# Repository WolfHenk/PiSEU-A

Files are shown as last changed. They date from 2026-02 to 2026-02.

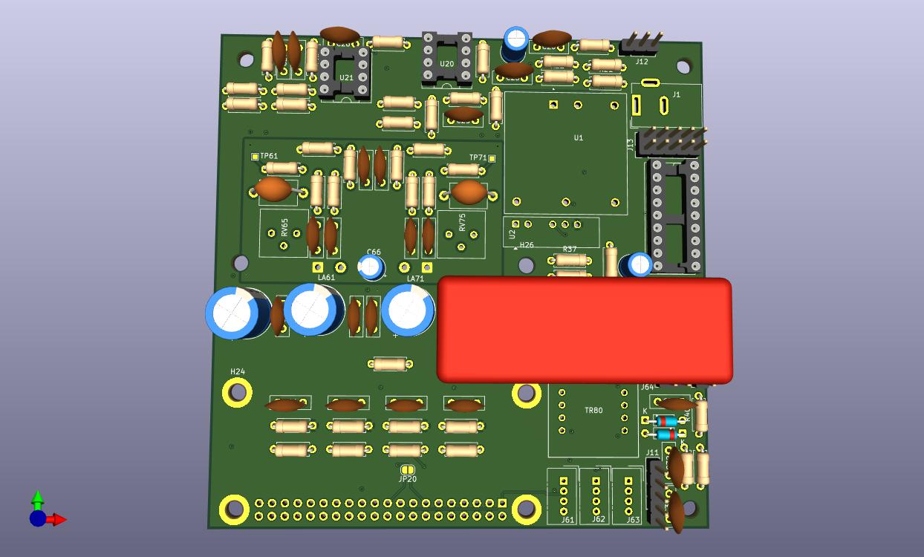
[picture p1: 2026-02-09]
PiSEU-A-v4-discrete.jpg

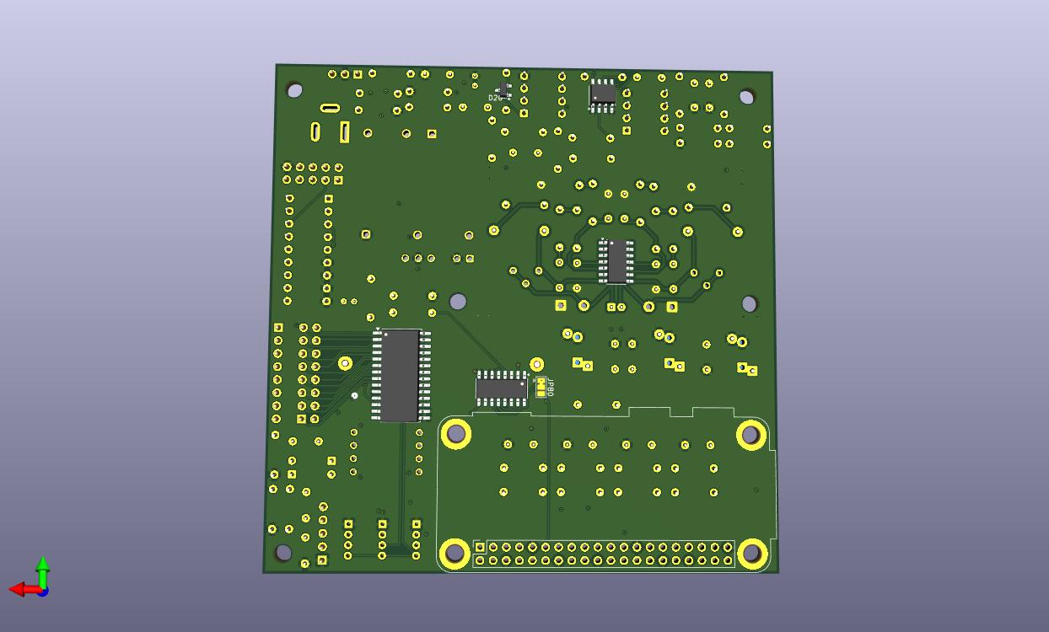
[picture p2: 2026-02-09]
PiSEU-A-v4-discrete-R.jpg

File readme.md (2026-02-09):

THE SEU (Sende-Empfangs-Umsetzer) translates TW39 to ED1000 and vice versa

SEU-A was at "Amt" the networks side of the line. SEU-B was at the telex at costumers side.

This card emulates SEU-A and sits between raspberry Pi (piTelex) and a ED1000 and works as a kind of modem between piTelex TXD and RXD and Telex

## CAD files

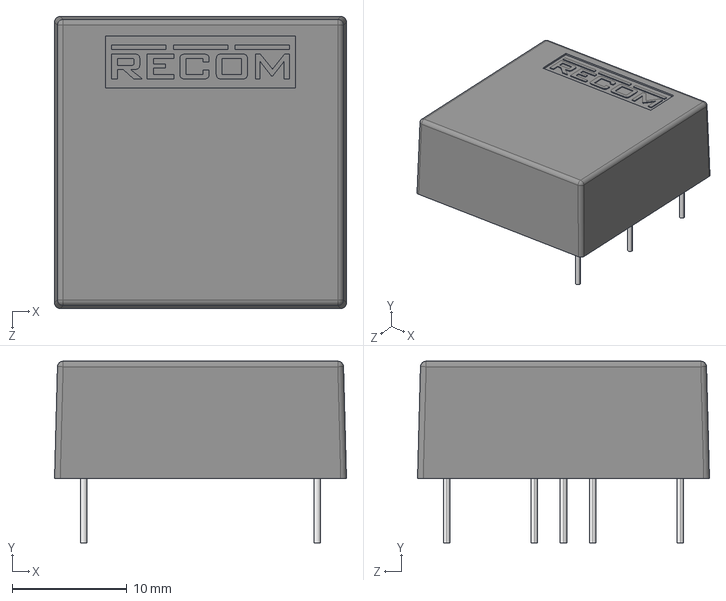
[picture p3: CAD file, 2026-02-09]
REC10K-2405DAW_H2/REC10K-2405DAW_H2.step
25.4 x 15.8 x 25.4 mm

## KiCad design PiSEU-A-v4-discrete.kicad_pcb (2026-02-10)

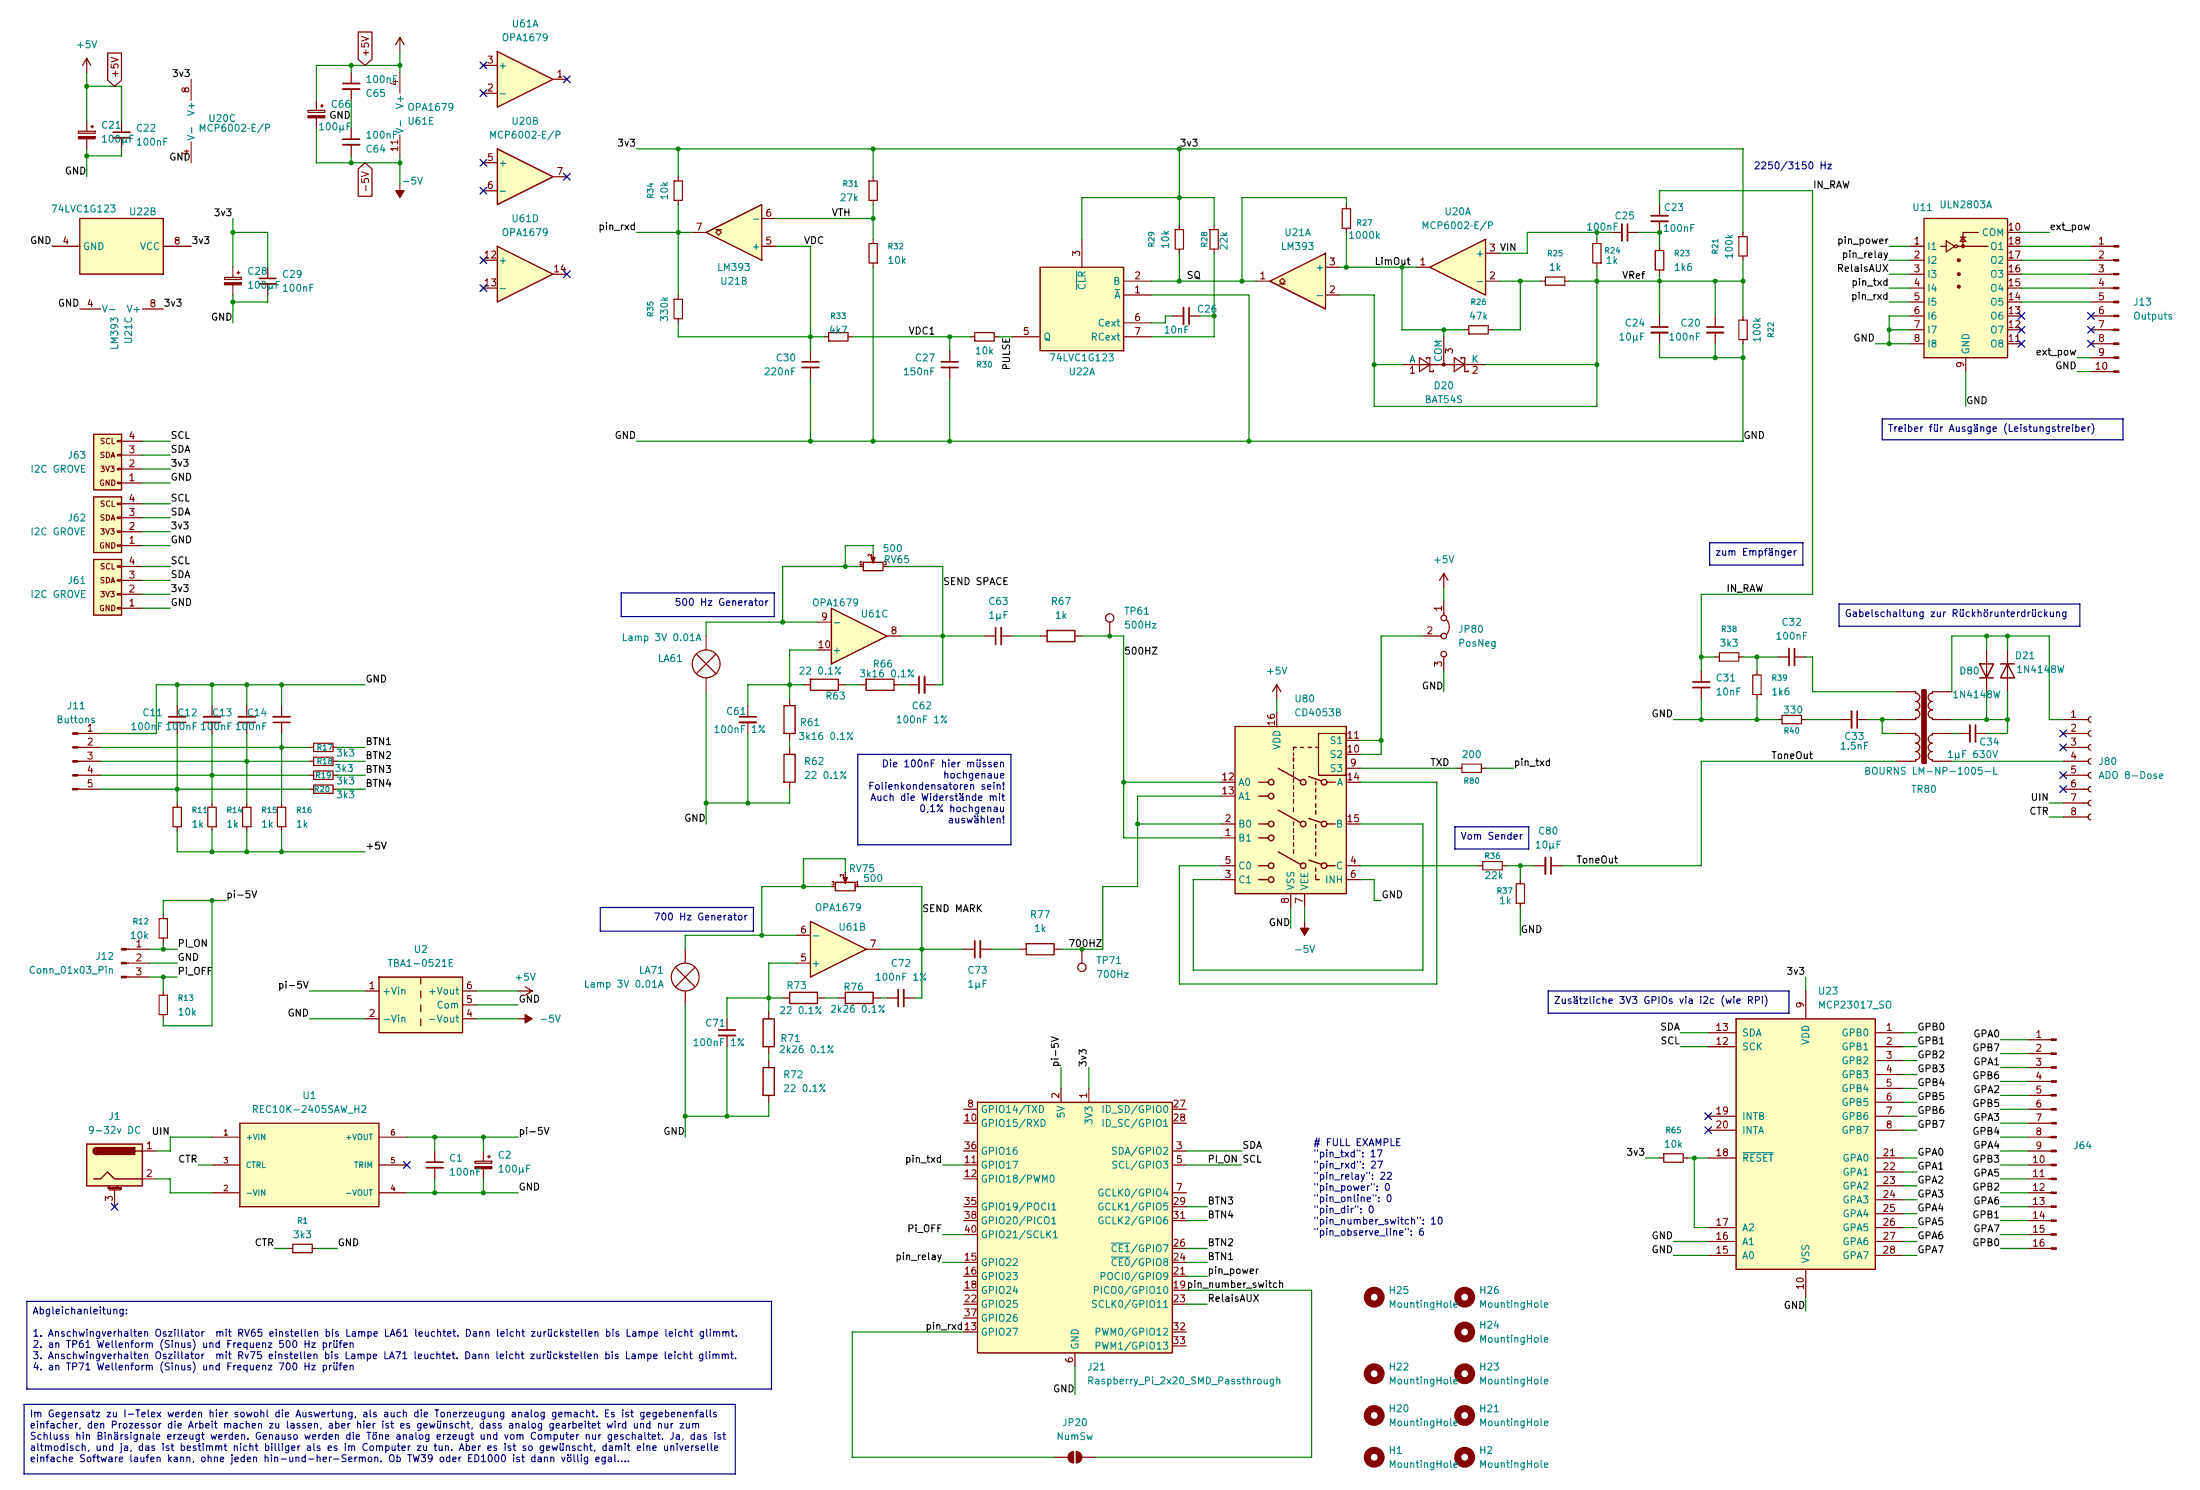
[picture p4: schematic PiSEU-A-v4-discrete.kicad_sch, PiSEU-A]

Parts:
C1, C11, C12, C13, C14, C20, C22, C23, C25, C29, C32, C64, C65: 100nF; C_Disc_D4.7mm_W2.5mm_P5.00mm; JLCPCB Part # C1590
C2, C21, C28: 100µF; CP_Radial_D6.3mm_P2.50mm; JLCPCB Part # C3338
C24, C80: 10µF; C_Radial_D5.0mm_H7.0mm_P2.00mm
C26, C31: 10nF; C_Disc_D5.0mm_W2.5mm_P2.50mm
C27: 150nF; C_Rect_L7.0mm_W4.5mm_P5.00mm; JLCPCB Part # C1597
C30: 220nF; C_Rect_L7.0mm_W4.5mm_P5.00mm; JLCPCB Part # C21120
C33: 1.5nF; C_Disc_D4.7mm_W2.5mm_P5.00mm; Part Number ggtt; JLCPCB Part # C1595
C34: 1µF 630V; C_Rect_L41.5mm_W15.0mm_P37.50mm_MKS4
C61, C62, C71, C72: 100nF 1%; C_Disc_D8.0mm_W2.5mm_P5.00mm
C63, C73: 1µF; C_Rect_L4.6mm_W3.8mm_P2.50mm_MKS02_FKP02; JLCPCB Part # C15849
C66: 100µF; CP_Radial_D6.3mm_P2.50mm
D20: BAT54S; SOT-23
D21, D80: 1N4148W; D_DO-35_SOD27_P7.62mm_Horizontal
H1, H2, H20, H21, H22, H23, H24, H25, H26: MountingHole; MountingHole_3.2mm_M3
J1: 9-32v DC; BarrelJack_Wuerth_6941xx301002
J11: Buttons; PinHeader_1x05_P2.54mm_Vertical
J12: Conn_01x03_Pin; PinHeader_1x03_P2.54mm_Vertical
J13: Outputs; PinHeader_2x05_P2.54mm_Vertical
J21: Raspberry_Pi_2x20_SMD_Passthrough; Raspberry_Pi_Zero_Socketed_THT_FaceDown_MountingHoles
J61, J62, J63: I2C GROVE; NS-Tech_Grove_1x04_P2mm_Vertical
J64: I2C-OUTPUTS; PinHeader_2x08_P2.54mm_Vertical; Part Number 1-1602FBV0T
J80: ADO 8-Dose; PinHeader_1x08_P2.54mm_Vertical
JP20: NumSw; SolderJumper-2_P1.3mm_Open_RoundedPad1.0x1.5mm
JP80: PosNeg; SolderJumper-3_P1.3mm_Bridged12_Pad1.0x1.5mm
LA61, LA71: Lamp 3V 0.01A; SolderWire-0.5sqmm_1x02_P4.6mm_D0.9mm_OD2.1mm
R1, R17, R18, R19, R20, R38: 3k3; R_Axial_DIN0207_L6.3mm_D2.5mm_P7.62mm_Horizontal; JLCPCB Part # C22978
R11, R14, R15, R16, R24, R25, R37, R67, R77: 1k; R_Axial_DIN0207_L6.3mm_D2.5mm_P7.62mm_Horizontal; JLCPCB Part # C21190
R12, R13, R29, R30, R32, R34, R65: 10k; R_Axial_DIN0207_L6.3mm_D2.5mm_P7.62mm_Horizontal; JLCPCB Part # C25804
R21, R22: 100k; R_Axial_DIN0207_L6.3mm_D2.5mm_P7.62mm_Horizontal; JLCPCB Part # C25803
R23, R39: 1k6; R_Axial_DIN0207_L6.3mm_D2.5mm_P7.62mm_Horizontal
R26: 47k; R_Axial_DIN0207_L6.3mm_D2.5mm_P7.62mm_Horizontal; JLCPCB Part # C25600
R27: 1000k; R_Axial_DIN0207_L6.3mm_D2.5mm_P7.62mm_Horizontal; JLCPCB Part # C22935
R28, R36: 22k; R_Axial_DIN0207_L6.3mm_D2.5mm_P7.62mm_Horizontal; JLCPCB Part # C31850
R31: 27k; R_Axial_DIN0207_L6.3mm_D2.5mm_P7.62mm_Horizontal; JLCPCB Part # C22967
R33: 4k7; R_Axial_DIN0207_L6.3mm_D2.5mm_P7.62mm_Horizontal
R35: 330k; R_Axial_DIN0207_L6.3mm_D2.5mm_P7.62mm_Horizontal
R40: 330; R_Axial_DIN0207_L6.3mm_D2.5mm_P7.62mm_Horizontal; JLCPCB Part # C23138
R61, R66: 3k16 0.1%; R_Axial_DIN0207_L6.3mm_D2.5mm_P7.62mm_Horizontal
R62, R63, R72, R73: 22 0.1%; R_Axial_DIN0207_L6.3mm_D2.5mm_P7.62mm_Horizontal
R71, R76: 2k26 0.1%; R_Axial_DIN0207_L6.3mm_D2.5mm_P7.62mm_Horizontal
R80: 200; R_Axial_DIN0207_L6.3mm_D2.5mm_P7.62mm_Horizontal; JLCPCB Part # C8218
RV65, RV75: 500; Potentiometer_Bourns_3386P_Vertical
TP61: 500Hz; TestPoint_Pad_1.0x1.0mm
TP71: 700Hz; TestPoint_Pad_1.0x1.0mm
TR80: BOURNS LM-NP-1005-L; TRANS_LM-NP-1005L_BRN
U1: REC10K-2405SAW_H2; CONV_REC10K-2405SAW_H2
U2: TBA1-0521E; Converter_DCDC_TRACO_TBA1-xxxxE_Dual_THT
U11: ULN2803A; DIP-18_W7.62mm_Socket
U20: MCP6002‑E/P; DIP-8_W7.62mm_Socket
U21: LM393; DIP-8_W7.62mm_Socket
U22: 74LVC1G123; SSOP-8_3.9x5.05mm_P1.27mm
U23: MCP23017_SO; SOIC-28W_7.5x17.9mm_P1.27mm
U61: OPA1679; SOIC-14_3.9x8.7mm_P1.27mm
U80: CD4053B; SOIC-16_3.9x9.9mm_P1.27mm; JLCPCB Part # C6742

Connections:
+5V: C21.1, C22.1, C65.1, C66.1, JP80.1 (A), R11.1, R14.1, R15.1, R16.1, U2.6 (+Vout), U61.4 (V+), U80.16 (VDD)
-5V: C64.2, C66.2, U2.4 (-Vout), U61.11 (V-), U80.7 (VEE)
/3v3: C28.1, C29.1, J21.1 (3V3), J21.17 (3V3), J61.2, J62.2, J63.2, R21.1, R28.1, R29.1, R31.1, R34.1, R65.1, U20.8 (V+), U21.8 (V+), U22.3 (~CLR), U22.8 (VCC), U23.9 (VDD)
/500HZ: R67.1, TP61.1, U80.1 (B1), U80.12 (A0)
/700HZ: R77.1, TP71.1, U80.2 (B0), U80.13 (A1)
/BTN1: J21.24 (~CE0/GPIO8), R17.2
/BTN2: J21.26 (~CE1/GPIO7), R18.2
/BTN3: J21.29 (GCLK1/GPIO5), R19.2
/BTN4: J21.31 (GCLK2/GPIO6), R20.2
/CTR: J80.8, R1.1, U1.3 (CTRL)
/GND: C1.2, C2.2, C11.2, C12.2, C13.2, C14.2, C20.2, C21.2, C22.2, C24.2, C27.2, C28.2, C29.2, C30.2, C31.2, C61.2, C64.1, C65.2, C71.2, J11.1, J12.2, J13.10, J21.6 (GND), J21.9 (GND), J21.14 (GND), J21.20 (GND), J21.25 (GND), J21.30 (GND), J21.34 (GND), J21.39 (GND), J61.1, J62.1, J63.1, JP80.3 (B), LA61.1 (-), LA71.1 (-), R1.2, R22.1, R32.1, R37.1, R39.1, R40.1, R62.2, R72.2, U1.4 (-VOUT), U2.2 (-Vin), U2.5 (Com), U11.6 (I6), U11.7 (I7), U11.8 (I8), U11.9 (GND), U20.4 (V-), U21.4 (V-), U22.1 (~A), U22.4 (GND), U23.10 (VSS), U23.15 (A0), U23.16 (A1), U80.6 (INH), U80.8 (VSS)
/GPA0: J64.1, U23.21 (GPA0)
/GPA1: J64.3, U23.22 (GPA1)
/GPA2: J64.5, U23.23 (GPA2)
/GPA3: J64.7, U23.24 (GPA3)
/GPA4: J64.9, U23.25 (GPA4)
/GPA5: J64.11, U23.26 (GPA5)
/GPA6: J64.13, U23.27 (GPA6)
/GPA7: J64.15, U23.28 (GPA7)
/GPB0: J64.16, U23.1 (GPB0)
/GPB1: J64.14, U23.2 (GPB1)
/GPB2: J64.12, U23.3 (GPB2)
/GPB3: J64.10, U23.4 (GPB3)
/GPB4: J64.8, U23.5 (GPB4)
/GPB5: J64.6, U23.6 (GPB5)
/GPB6: J64.4, U23.7 (GPB6)
/GPB7: J64.2, U23.8 (GPB7)
/IN_RAW: C23.1, C31.1, R38.1
/LimOut: D20.3 (COM), R26.1, R27.1, U20.1, U21.3 (+)
/PI_ON: J12.1, J21.5 (SCL/GPIO3), J61.4, J62.4, J63.4, R12.2, U23.12 (SCK)
/PULSE: R30.2, U22.5 (Q)
/Pi_OFF: J12.3, J21.40 (GPIO21/SCLK1), R13.1
/RelaisAUX: J21.23 (SCLK0/GPIO11), U11.3 (I3)
/SDA: J21.3 (SDA/GPIO2), J61.3, J62.3, J63.3, U23.13 (SDA)
/SEND MARK: C72.2, C73.1, RV75.1, U61.7
/SEND SPACE: C62.2, C63.1, RV65.3, U61.8
/SQ: R27.2, R29.2, U21.1, U22.2 (B)
/TXD: R80.2, U80.9 (S3)
/ToneOut: C80.1, TR80.8
/UIN: J1.1, J80.7, U1.1 (+VIN)
/VDC: C30.1, R33.1, R35.2, U21.5 (+)
/VDC1: C27.1, R30.1, R33.2
/VIN: C25.2, R24.2, U20.3 (+)
/VRef: C20.1, C24.1, D20.1 (A), D20.2 (K), R21.2, R22.2, R23.1, R24.1, R25.2, U21.2 (-)
/VTH: R31.2, R32.2, U21.6 (-)
/ext_pow: J13.9, U11.10 (COM)
/pi-5V: C1.1, C2.1, J21.2 (5V), J21.4 (5V), R12.1, R13.2, U1.6 (+VOUT), U2.1 (+Vin)
/pin_number_switch: J21.19 (PICO0/GPIO10), JP20.2 (B)
/pin_power: J21.21 (POCI0/GPIO9), U11.1 (I1)
/pin_relay: J21.15 (GPIO22), U11.2 (I2)
/pin_rxd: J21.13 (GPIO27), JP20.1 (A), R34.2, R35.1, U11.5 (I5), U21.7
/pin_txd: J21.11 (GPIO17), R80.1, U11.4 (I4)
unnamed: C23.2, C25.1, R23.2
unnamed: C32.1, TR80.5
unnamed: C32.2, R38.2, R39.2
unnamed: C33.1, TR80.6, TR80.7
unnamed: C33.2, R40.2
unnamed: C34.2, TR80.2
unnamed: C62.1, R66.1
unnamed: C63.2, R67.2
unnamed: C72.1, R76.1
unnamed: C73.2, R77.2
unnamed: C80.2, R36.2, R37.2
unnamed: C34.1, D21.2 (A), D80.1 (K), TR80.3
unnamed: D21.1 (K), D80.2 (A), J80.1, TR80.4
unnamed: C14.1, J11.2, R16.2, R17.1
unnamed: C13.1, J11.3, R15.2, R18.1
unnamed: C12.1, J11.4, R14.2, R19.1
unnamed: C11.1, J11.5, R11.2, R20.1
unnamed: J13.1, U11.18 (O1)
unnamed: J13.2, U11.17 (O2)
unnamed: J13.3, U11.16 (O3)
unnamed: J13.4, U11.15 (O4)
unnamed: J13.5, U11.14 (O5)
unnamed: J80.4, TR80.1
unnamed: JP80.2 (C), U80.10 (S2), U80.11 (S1)
unnamed: LA61.2 (+), RV65.1, RV65.2, U61.9 (-)
unnamed: LA71.2 (+), RV75.2, RV75.3, U61.6 (-)
unnamed: R61.2, R62.1
unnamed: R63.1, R66.2
unnamed: R71.2, R72.1
unnamed: R73.1, R76.2
unnamed: J1.2, U1.2 (-VIN)
unnamed: R25.1, R26.2, U20.2 (-)
unnamed: C26.2, U22.6 (Cext)
unnamed: C26.1, R28.2, U22.7 (RCext)
unnamed: R65.2, U23.17 (A2), U23.18 (~RESET)
unnamed: C71.1, R71.1, R73.2, U61.5 (+)
unnamed: C61.1, R61.1, R63.2, U61.10 (+)
unnamed: U80.5 (C0), U80.14 (A)
unnamed: U80.3 (C1), U80.15 (B)
unnamed: R36.1, U80.4 (C)

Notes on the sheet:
# FULL EXAMPLE "pin_txd": 17 "pin_rxd": 27 "pin_relay": 22 "pin_power": 0 "pin_online": 0 "pin_dir": 0 "pin_number_switch": 10 "pin_observe_line": 6
2250/3150 Hz
Zusätzliche 3V3 GPIOs via i2c (wie RPi)
Die 100nF hier müssen hochgenaue Folienkondensatoren sein! Auch die Widerstände mit 0,1% hochgenau auswählen!
500 Hz Generator
Im Gegensatz zu I-Telex werden hier sowohl die Auswertung, als auch die Tonerzeugung analog gemacht. Es ist gegebenenfalls einfacher, den Prozessor die Arbeit machen zu lassen, aber hier ist es gewünscht, dass analog gearbeitet wird und nur zum Schluss hin Binärsignale erzeugt werden. Genauso werde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
Vom Sender
zum Empfänger
Abgleichanleitung: 1. Anschwingverhalten Oszillator mit RV65 einstellen bis Lampe LA61 leuchtet. Dann leicht zurückstellen bis Lampe leicht glimmt. 2. an TP61 Wellenform (Sinus) und Frequenz 500 Hz prüfen 3. Anschwingverhalten Oszillator mit Rv75 einstellen bis Lampe LA71 leuchtet. Dann leicht zurü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
Treiber für Ausgänge (Leistungstreiber)
Gabelschaltung zur Rückhörunterdrückung
700 Hz Generator

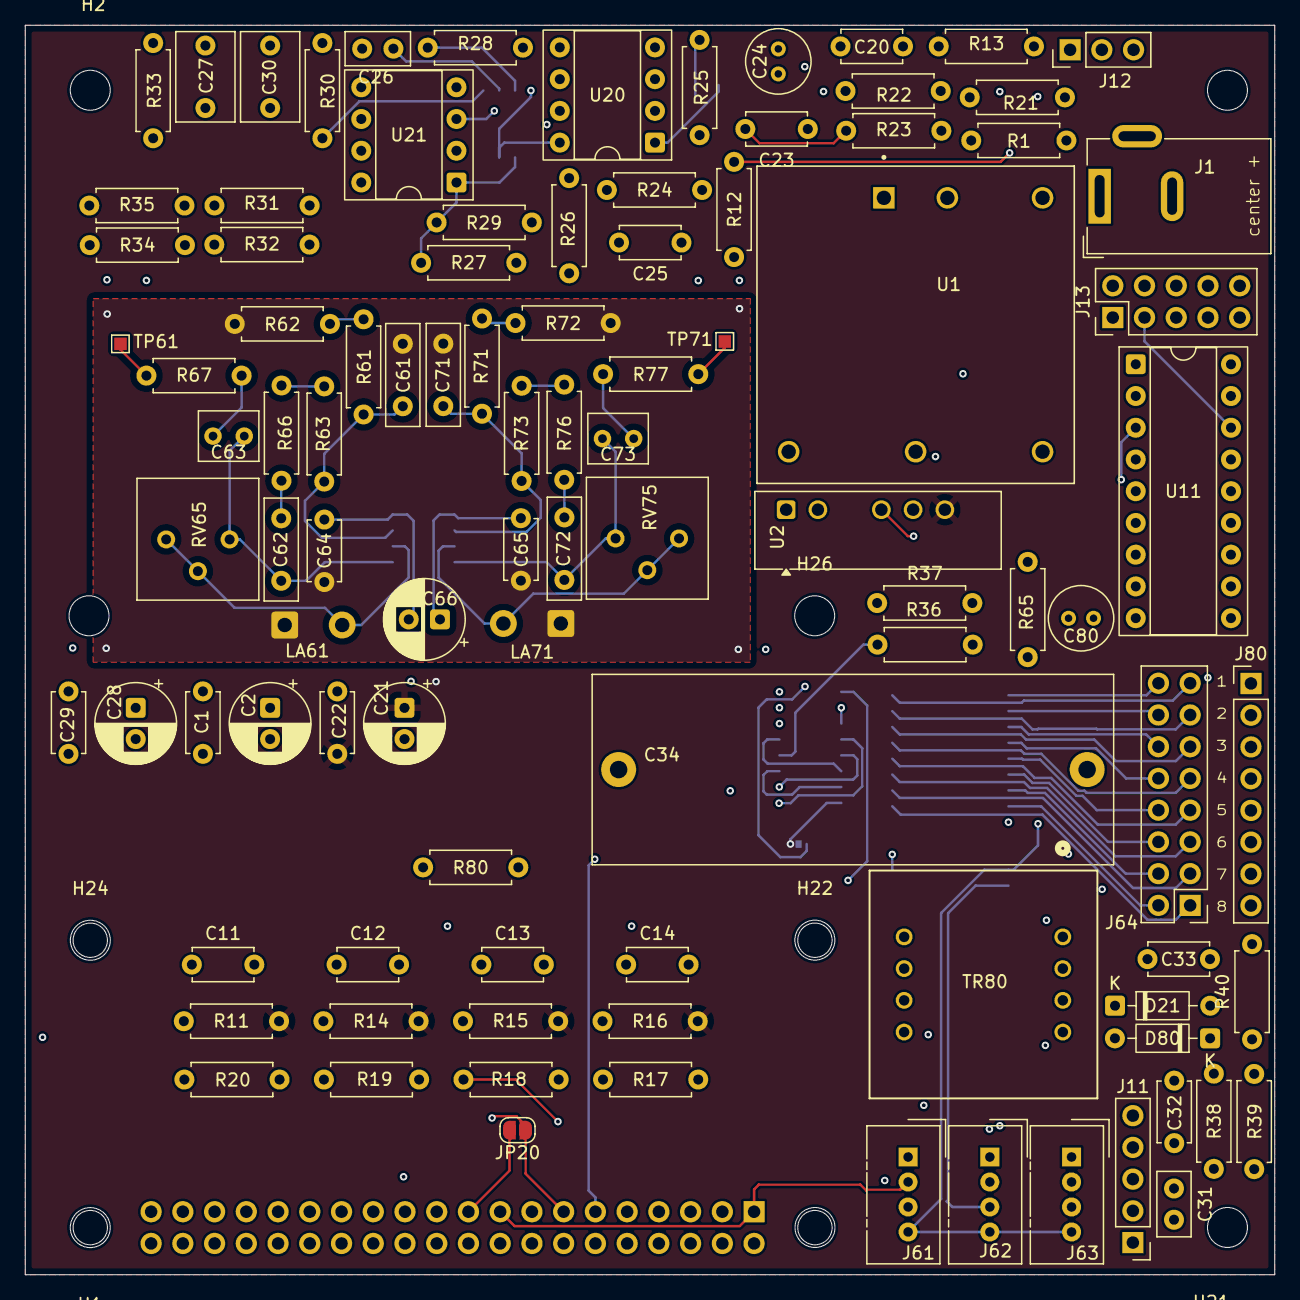
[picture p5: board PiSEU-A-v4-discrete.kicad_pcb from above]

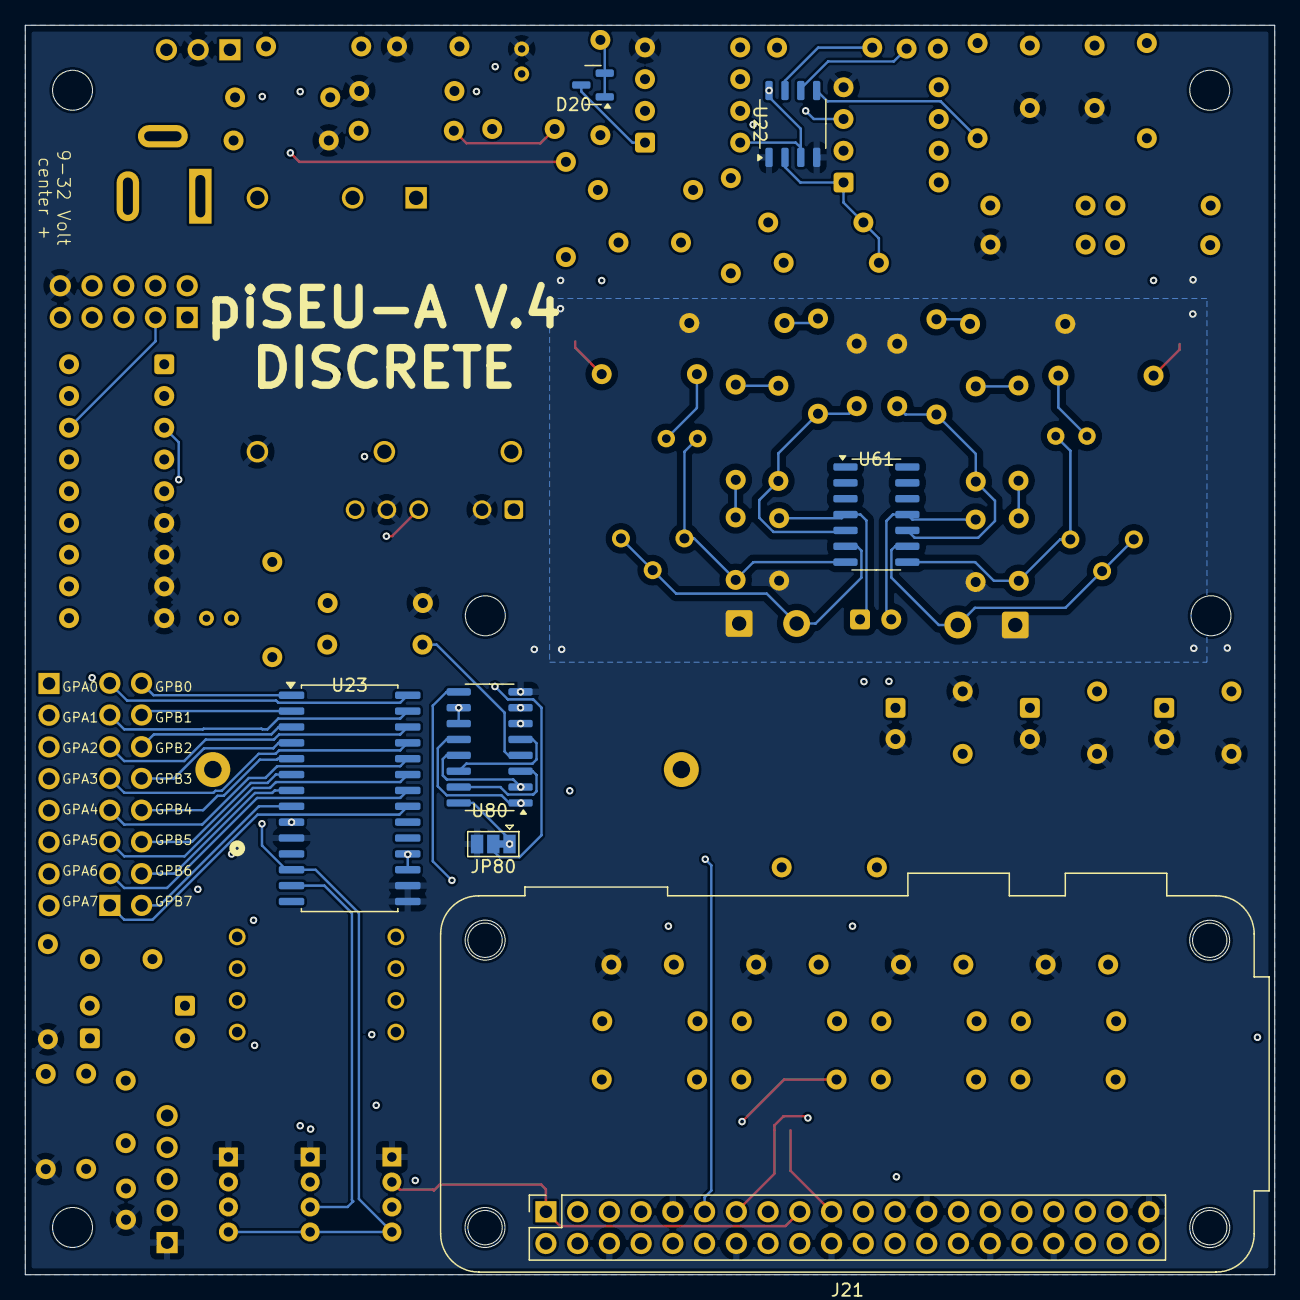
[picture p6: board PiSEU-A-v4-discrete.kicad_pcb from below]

Board: 4 copper layers, 100.0 x 100.0 mm, 114 parts (7 on the bottom side), 92 nets.
